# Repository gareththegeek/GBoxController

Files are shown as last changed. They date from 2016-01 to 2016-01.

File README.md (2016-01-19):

# GBoxController

Design for a 31 button USB Windows game controller built using an ATMega328 microcontroller for use with Flight Simulators.

This software was built using the following tools and libraries

<a href="https://www.obdev.at/products/vusb/index.html">V-USB</a><br/>
<a href="http://www.atmel.com/tools/STUDIOARCHIVE.aspx">Atmel Studio 6.2</a><br/>
<a href="https://www.arduino.cc/en/Main/Software">Arduino IDE</a><br/>
<a href="https://code.google.com/p/diy-layout-creator/">DIY Layout Creator</a><br/>
<a href="http://fritzing.org/home/">Fritzing</a><br/>

The device utilises the built in Windows human interface device (HID) driver and should appear in the Control Panel under Game Controllers as a 31 button device.  The controller has:
<ul><li>8 x two way switches (one button each)
<li>4 x three way switches (two buttons each)
<li>5 x rotary encoders with push buttons (three buttons each)</ul>

See the schematics folder for logical and physical circuit diagrams.  I have included png renderings of these diagrams in case you don't have/want the relevant software to view them.

In order to load onto the ATMega chip, I used the Arduino IDE with an Arduino Uno to act as the in service programmer (ISP).  See <a href="https://www.arduino.cc/en/Tutorial/ArduinoISP">this tutorial</a> for an example of how to do this.  The circuit design contains a standard 6 pin ISP socket for this purpose.

The Atmel Studio solution will compile to a binary .hex file.  I found it necessary to modify the Arduino IDE's boards.txt to include an additional entry entitled 'ATMega' which pointed to the location of the compiled binary file in order to use the Arduino ISP.

The controller is designed to send a pulse (button press) each time the state of a switch changes. For example, moving a two way switch up, down, up will result in three separate button presses for the corresponding button.

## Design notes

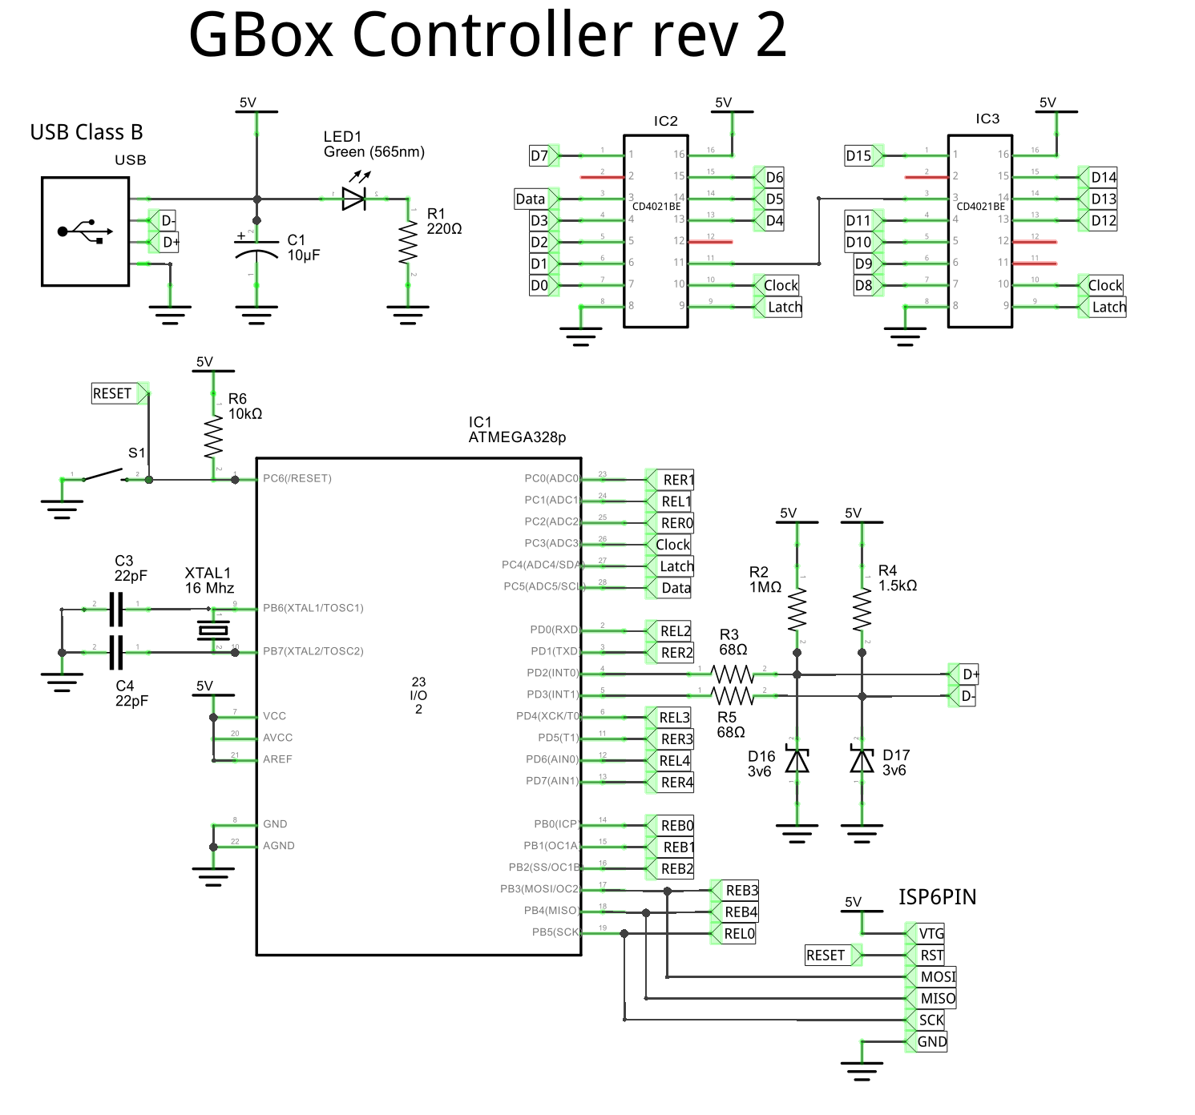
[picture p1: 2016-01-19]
Schematics/Schematic page 1.png

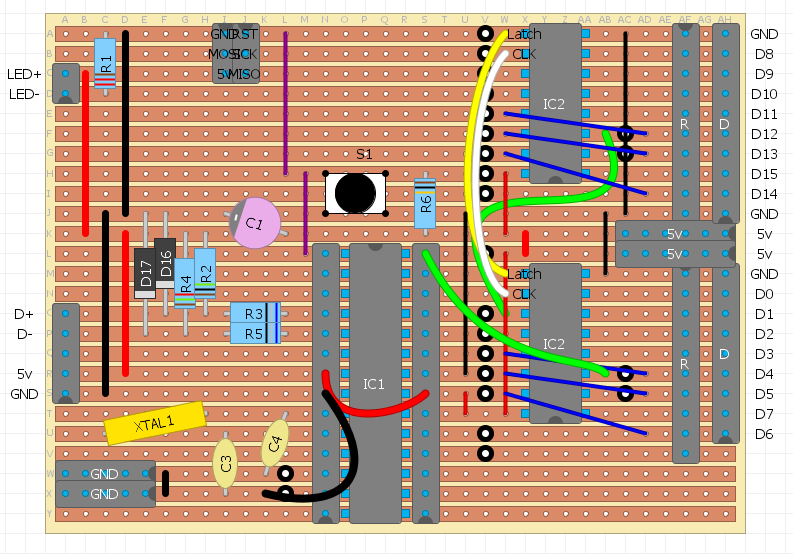
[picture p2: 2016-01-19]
Schematics/Board.png

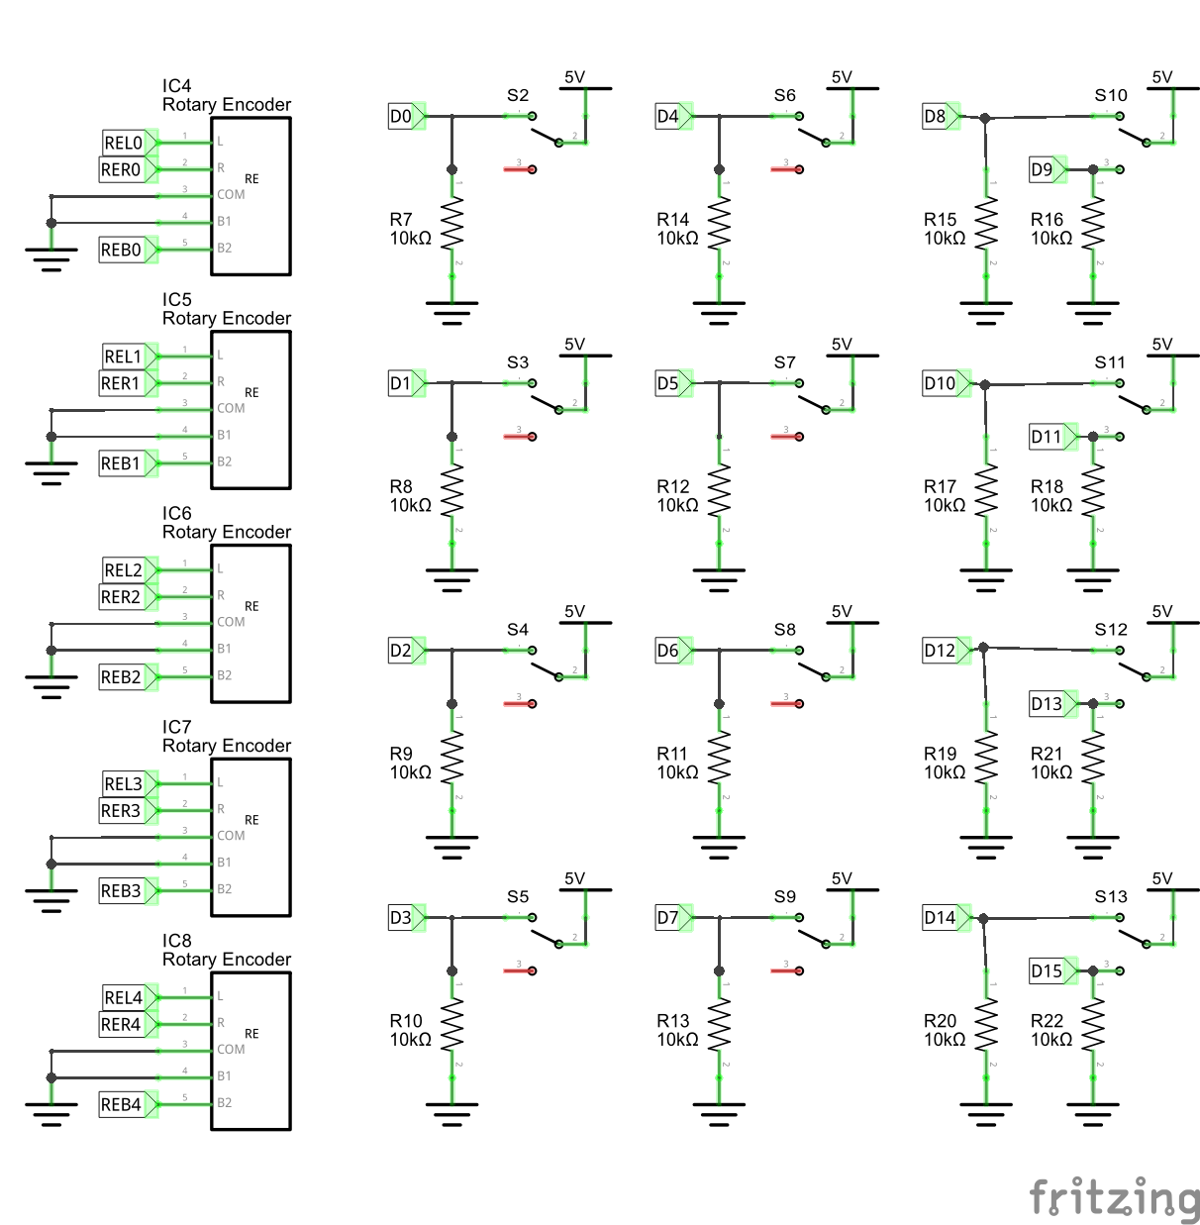
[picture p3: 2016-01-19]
Schematics/Schematic page 2.png

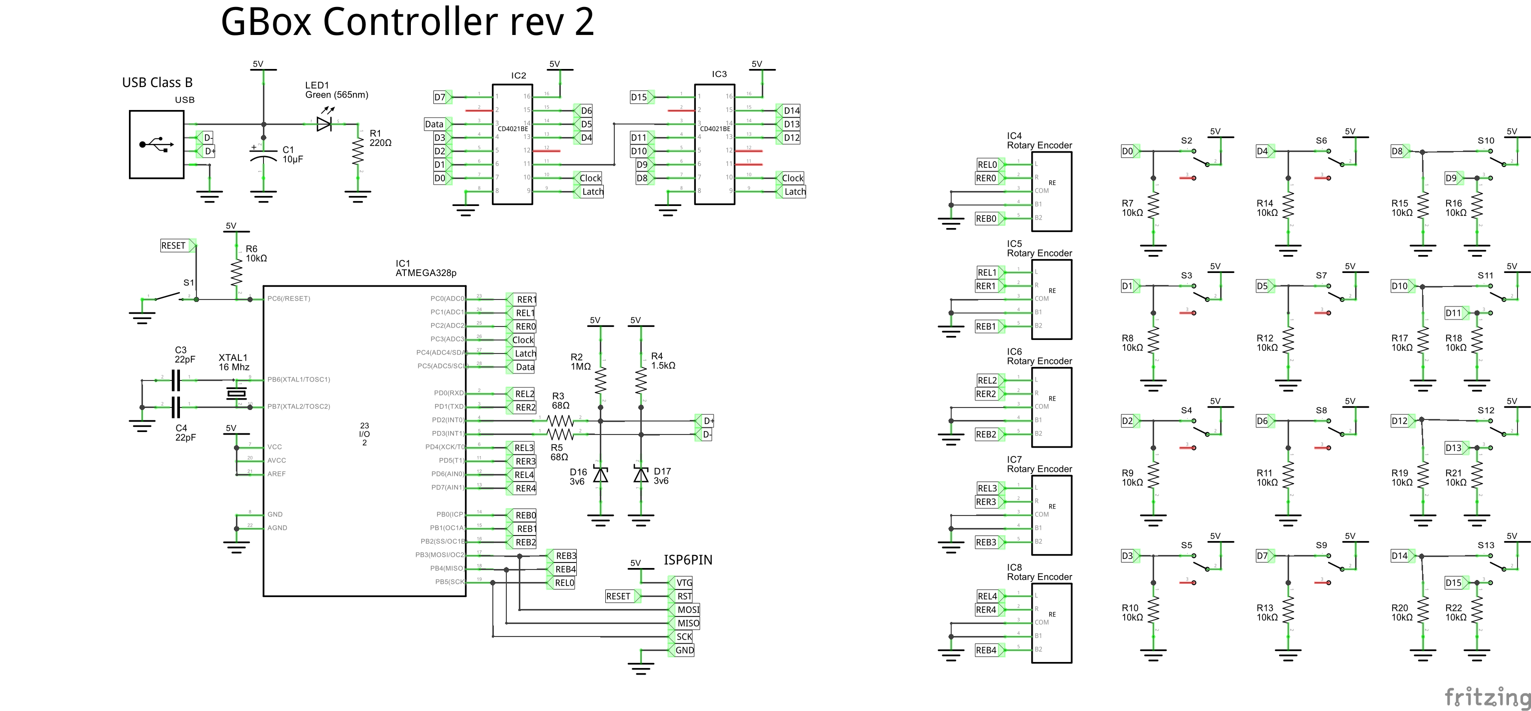
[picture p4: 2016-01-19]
Schematics/Schematic_schem.png

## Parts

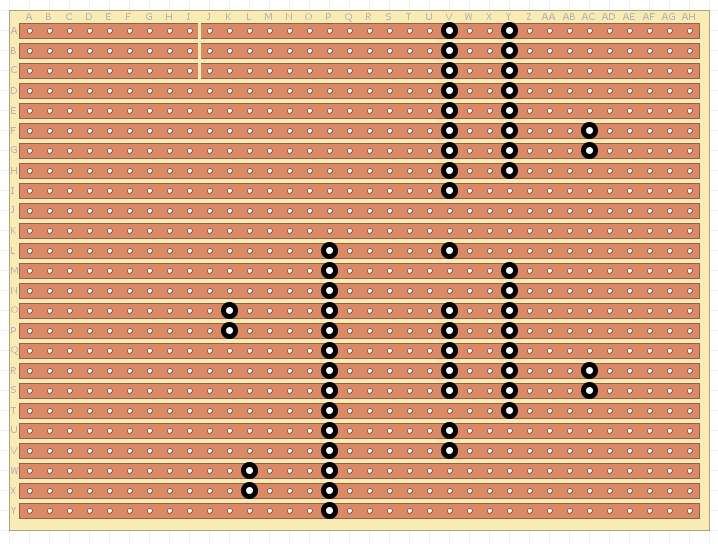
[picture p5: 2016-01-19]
Schematics/Board no components.png

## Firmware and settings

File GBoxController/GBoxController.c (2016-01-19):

// please see http://frank.circleofcurrent.com/index.php?page=hid_tutorial_1
// the "usb_hid_rpt_desc.hid" file needs to be viewed with the HID Descriptor Tool from USB.org

// required headers
#define F_CPU 16000000L
#include <avr/io.h>
#include <avr/wdt.h>
#include <avr/interrupt.h>
#include <util/delay.h>
#include <avr/pgmspace.h>
#include <string.h>

// What the Pins do
// 1   PC6: RESET
// 2   PD0: Rotary Encoder 2 L
// 3   PD1: Rotary Encoder 2 R
// 4   PD2: USB D+
// 5   PD3: USB D-
// 6   PD4: Rotary Encoder 3 L
// 7   VCC: 5v
// 8   GND: 0v
// 9   PB6: CLK
// 10  PB7: CLK
// 11  PD5: Rotary Encoder 3 R
// 12  PD6: Rotary Encoder 4 L
// 13  PD7: Rotary Encoder 4 R
// 14  PB0: REB0 - Rotary Encoder 0 Button
// 15  PB1: REB1 - Rotary Encoder 1 Button
// 16  PB2: REB2 - Rotary Encoder 2 Button
// 17  PB3: REB3 - Rotary Encoder 3 Button
// 18  PB4: REB4 - Rotary Encoder 4 Button
// 19  PB5: Rotary Encoder 0 L
// 20  VCC: 5v
// 21 AREF: 5v 
// 22  GND: 0v
// 23  PC0: Rotary Encoder 1 R
// 24  PC1: Rotary Encoder 1 L
// 25  PC2: Rotary Encoder 0 R
// 26  PC3: Clock - Shift Register
// 27  PC4: Latch - Shift Register
// 28  PC5: Data In - Shift Register

// V-USB
#include "usbdrv/usbdrv.h"

#define CD4021BE_LATCH_PIN PINC4
#define CD4021BE_CLOCK_PIN PINC3
#define CD4021BE_DATA_PIN PINC5

#define REB0 PINB0
#define REB1 PINB1
#define REB2 PINB2
#define REB3 PINB3
#define REB4 PINB4

#define USAGE(x) 0x9, x, // Usage
#define USAGE2(x, y) 0xA, x, y, // Usage
#define USAGE_PAGE(x) 0x5, x, // Usage Page
#define USAGE_PAGE2(x, y) 0x6, x, y, // Usage Page
#define USAGE_MINIMUM(x) 0x19, x, // Usage Minimum
#define USAGE_MAXIMUM(x) 0x29, x, // Usage Maximum
#define COLLECTION(x) 0xA1, x, // Collection
#define END_COLLECTION 0xC0, // End Collection
#define REPORT_ID(x) 0x85, x, // Report
#define REPORT_SIZE(x) 0x75, x, // Report Size
#define REPORT_COUNT(x) 0x95, x, // Report Count
#define LOGICAL_MINIMUM(x) 0x15, x, // Logical Minimum
#define LOGICAL_MINIMUM2(x, y) 0x16, x, y, // Logical Minimum
#define LOGICAL_MINIMUM4(x, y, z, w) 0x17, x, y, z, w, // Logical Minimum
#define LOGICAL_MAXIMUM(x) 0x25, x, // Logical Maximum
#define LOGICAL_MAXIMUM2(x, y) 0x26, x, y, // Logical Maximum
#define LOGICAL_MAXIMUM4(x, y, z, w) 0x27, x, y, z, w, // Logical Maximum
#define PHYSICAL_MINIMUM(x) 0x35, x,
#define PHYSICAL_MAXIMUM(x) 0x45, x,
#define PHYSICAL_MAXIMUM2(x, y) 0x46, x, y,
#define PHYSICAL_MAXIMUM4(x, y, z, w) 0x47, x, y, z, w,
#define OUTPUT(x) 0x91, x, // Output
#define INPUT(x) 0x81, x, // Input
#define FEATURE(x) 0xB1, x, // Feature
#define UNIT(x, y) 0x65, x,
#define UNIT2(x, y) 0x66, x, y,
#define UNIT_EXPONENT(x) 0x55, ((x) & 0x0f),

#define GENERIC_DESKTOP 0x1
#define GAME_PAD 0x5
#define APPLICATION 0x1
#define X 0x30
#define Y 0x31
#define Z 0x32
#define Rx 0x33
#define Ry 0x34
#define Rz 0x35
#define SLIDER 0x36
#define DIAL 0x37
#define DATA_VAR_ABS 0x2
#define CNST_VAR_ABS 0x3
#define BUTTON 0x9
#define PHYSICAL 0x0

PROGMEM const char usbHidReportDescriptor[USB_CFG_HID_REPORT_DESCRIPTOR_LENGTH] = {
	USAGE_PAGE(GENERIC_DESKTOP)
	USAGE(GAME_PAD)
	COLLECTION(APPLICATION)
		COLLECTION(PHYSICAL)
			USAGE_PAGE(BUTTON)
			USAGE_MINIMUM(1)
			USAGE_MAXIMUM(31)
			LOGICAL_MINIMUM(0)
			LOGICAL_MAXIMUM(1)
			REPORT_COUNT(31)
			REPORT_SIZE(1)
			INPUT(DATA_VAR_ABS)
			REPORT_COUNT(1)
			REPORT_SIZE(1)
			INPUT(CNST_VAR_ABS)
		END_COLLECTION
	END_COLLECTION
};

typedef struct
{
	uint8_t buttons0;
	uint8_t buttons1;
	uint8_t buttons2;
	uint8_t buttons3;
	
} gamepad_report_t;

static uint8_t idle_rate = 500 / 4; // see HID1_11.pdf sect 7.2.4
static uint8_t protocol_version = 0; // see HID1_11.pdf sect 7.2.6

static volatile gamepad_report_t gamepad_report;
static volatile gamepad_report_t gamepad_report_old;

usbMsgLen_t usbFunctionSetup(uint8_t data[8])
{
	// see HID1_11.pdf sect 7.2 and http://vusb.wikidot.com/driver-api
	usbRequest_t *rq = (void *)data;

	if ((rq->bmRequestType & USBRQ_TYPE_MASK) != USBRQ_TYPE_CLASS)
		return 0; // ignore request if it's not a class specific request

	// see HID1_11.pdf sect 7.2
	switch (rq->bRequest)
	{
		case USBRQ_HID_GET_IDLE:
			usbMsgPtr = &idle_rate; // send data starting from this byte
			return 1; // send 1 byte
		case USBRQ_HID_SET_IDLE:
			idle_rate = rq->wValue.bytes[1]; // read in idle rate
			return 0; // send nothing
		case USBRQ_HID_GET_PROTOCOL:
			usbMsgPtr = &protocol_version; // send data starting from this byte
			return 1; // send 1 byte
		case USBRQ_HID_SET_PROTOCOL:
			protocol_version = rq->wValue.bytes[1];
			return 0; // send nothing
		case USBRQ_HID_GET_REPORT:
			usbMsgPtr = (uchar*)&gamepad_report;
			return sizeof(gamepad_report);
		case USBRQ_HID_SET_REPORT: // no "output" or "feature" implemented, so ignore
			return 0; // send nothing
		default: // do not understand data, ignore
			return 0; // send nothing
	}
}

// this function is used to guarantee that the data is sent to the computer once
void usbSendHidReport(uchar * data, uchar len)
{
	while(1)
	{
		usbPoll();
		if (usbInterruptIsReady())
		{
			usbSetInterrupt(data, len);
			break;
		}
	}
}

static void hardwareInit(void)
{
	// TODO: Not sure but I think this may be required if I implement the watchdog
	
	//uchar i = 0;
	//uchar j = 0;

	//PORTB	= 0xff;   // Activate all pull-ups
	//DDRB	= 0x00;   // All pins input
	//PORTC	= 0xff;   // Activate all pull-ups
	//DDRC	= 0x00;   // All pins input
	//PORTD	= 0xfa;   // 1111 1010 bin: activate pull-ups except on USB lines
	//DDRD	= 0x05;   // 0000 0101 bin: all pins input except USB (-> USB reset)
	//while(--j)
	//{
		//// USB Reset by device only required on Watchdog Reset
		//while(--i); // Delay >10ms for USB reset
	//}
	//DDRD = 0x00;    // 0000 0000 bin: remove USB reset condition
	
	// Configure timer 0 for a rate of 16M/(1024 * 256) = 61.04 Hz (~16ms)
	//TCCR0B = 5;      // Timer0 prescaler: 1024
	
	//DDRD |= (1<<DDD1);
	//PORTD |= (1<<PORTD1);
	
	// Digital Pins //
	
	PORTB = 0xff;	// Activate pull-ups
	DDRB = 0x00;	// All pins are input
	PORTD = 0xf3;	// Activate pull-ups (except USB pins)
	DDRD = 0x00;	// All pins are input
	
	PORTC = 0xc7;	// Activate pull-ups (except shift register)
	
	DDRC =
		(1 << CD4021BE_LATCH_PIN) |
		(1 << CD4021BE_CLOCK_PIN);	// Enable write on latch and clock pins only
		
	// Enable interrupts for rotary encoders
	PCMSK0 |= (1 << PCINT5);
	PCMSK1 |= (1 << PCINT8) | (1 << PCINT9) | (1 << PCINT10);
	PCMSK2 |= (1 << PCINT16) | (1 << PCINT17) | (1 << PCINT20) | (1 << PCINT21) | (1 << PCINT22) | (1 << PCINT23);
	
	PCICR |= (1 << PCIE0);
	PCICR |= (1 << PCIE1);
	PCICR |= (1 << PCIE2);
}

#define CHANGE_BUFFER_LENGTH 128
static volatile gamepad_report_t changeBuffer[CHANGE_BUFFER_LENGTH];
static volatile uint8_t changeBufferIndex;

static volatile gamepad_report_t currentState;
static volatile gamepad_report_t previousState;

#define ROTARY_ENCODER_COUNT 10
static int8_t encval[ROTARY_ENCODER_COUNT];
static uint8_t old_AB[ROTARY_ENCODER_COUNT];

static const int8_t enc_states [] PROGMEM =
	{0,-1,1,0,1,0,0,-1,-1,0,0,1,0,1,-1,0};  //encoder lookup table

static void readEncoder(uint8_t reindex, uint8_t data, uint8_t leftValue, uint8_t rightValue)
{	
	old_AB[reindex] <<=2;  //remember previous state
	old_AB[reindex] |= data;
	encval[reindex] += pgm_read_byte(&(enc_states[( old_AB[reindex] & 0x0f )]));
	
	if (encval[reindex] > 3)
	{
		encval[reindex] = 0;
		
		if(leftValue >= 8)
		{
			leftValue -= 8;
			previousState.buttons3 &= ~(1 << leftValue);
			currentState.buttons3 |= (1 << leftValue);
		}
		else
		{
			previousState.buttons2 &= ~(1 << leftValue);
			currentState.buttons2 |= (1 << leftValue);
		}
	}
	else if (encval[reindex] < -3)
	{
		encval[reindex] = 0;
		
		if(rightValue >= 8)
		{
			rightValue -= 8;
			previousState.buttons3 &= ~(1 << rightValue);
			currentState.buttons3 |= (1 << rightValue);
		}
		else
		{
			previousState.buttons2 &= ~(1 << rightValue);
			currentState.buttons2 |= (1 << rightValue);
		}
	}
}

#define ROTARY_ENCODER0 readEncoder(0, ( (PINB & (1 << PINB5)) >> 4 ) | ( (PINC & (1 << PINC2)) >> 2 ), 5, 6)
#define ROTARY_ENCODER1 readEncoder(1, ( (PINC & ( (1 << PINC0) | (1 << PINC1) ))      ), 7, 8)
#define ROTARY_ENCODER2 readEncoder(2, ( (PIND & ( (1 << PIND0) | (1 << PIND1) ))      ), 9, 10)
#define ROTARY_ENCODER3 readEncoder(3, ( (PIND & ( (1 << PIND4) | (1 << PIND5) )) >> 4 ), 11, 12)
#define ROTARY_ENCODER4 readEncoder(4, ( (PIND & ( (1 << PIND6) | (1 << PIND7) )) >> 6 ), 13, 14)

static uint8_t previousPINB;
static uint8_t previousPINC;
static uint8_t previousPIND;

ISR(PCINT0_vect)
{
	// Figure out which pin triggered the interrupt
	
	uint8_t pinB = PINB & 0x20; /*00100000 PB5*/
	
	uint8_t changeB = previousPINB ^ pinB;
	
	previousPINB = pinB;
	
	if (changeB != 0)
	{
		// Rotary Encoder 0 on pins PB5 and PC3
		ROTARY_ENCODER0;
	}
}

ISR(PCINT1_vect)
{
	// Figure out which pin triggered the interrupt
	
	uint8_t pinC = PINC & 0x07; /*00000111 PB0-PB2*/
	
	uint8_t changeC = previousPINC ^ pinC;
	
	previousPINC = pinC;
	
	if (changeC & (1 << PINC2))
	{
		// Rotary Encoder 0 on pins PB5 and PC2
		ROTARY_ENCODER0;
	}
	
	if(changeC & ( (1 << PINC0) | (1 << PINC1) ))
	{
		// Rotary Encoder 1 on pins PC0 and PC1
		ROTARY_ENCODER1;
	}
}

ISR(PCINT2_vect)
{
	// Figure out which pin triggered the interrupt
	
	uint8_t pinD = PIND & 0xf3; /*11110011 PD0-PD1 PD4-PD7*/
	
	uint8_t changeD = previousPIND ^ pinD;
	
	previousPIND = pinD;
	
	if(changeD != 0)
	{
		if (changeD & ((1 << PIND0) | (1 << PIND1)))
		{
			// Rotary Encoder 2 on pins PD0 and PD1
			ROTARY_ENCODER2;
		}
		if (changeD & ((1 << PIND4) | (1 << PIND5)))
		{
			// Rotary Encoder 3 on pins PD4 and PD5
			ROTARY_ENCODER3;
		}
		if (changeD & ((1 << PIND6) | (1 << PIND7)))
		{
			// Rotary Encoder 4 on pins PD6 and PD7
			ROTARY_ENCODER4;
		}
	}
}

static void clockPulse(uint8_t clockPin)
{
	PINC |= (1 << clockPin);
	_delay_us(0.2d);
	PINC &= ~(1 << clockPin);
	_delay_us(0.2d);
}

static void latch(uint8_t latchPin)
{
	//Pulse the latch pins:
	//set them to 1 to collect parallel data
	PINC |= (1 << latchPin);
	//set it to 1 to collect parallel data, wait
	_delay_us(20.0d);
	//set it to 0 to transmit data serially
	PINC &= ~(1 << latchPin);
	//_delay_us(10.0d);
}

static uint8_t shiftIn(uint8_t dataPin, uint8_t clockPin)
{	
	int8_t i;
	uint8_t temp;
	uint8_t data = 0;
	
	clockPulse(clockPin);
	
	for (i = 7; i >= 0; i--)
	{
		temp = PINC;
		_delay_us(0.2d);
		
		temp &= (1 << dataPin);
		temp >>= dataPin;
		
		data |= (temp << i);
		
		// HACK: Contrary to all tutorials and the 4021 chip's data-,
		// I seem to have to use two clock pulses instead of one.
		// Clearly I have misunderstood something here but this code
		// works so I'm going with it!
		clockPulse(clockPin);
		clockPulse(clockPin);
	}
	
	return data;
}

static void updateReport()
{	
	latch(CD4021BE_LATCH_PIN);
	
	currentState.buttons0 = shiftIn(CD4021BE_DATA_PIN, CD4021BE_CLOCK_PIN);
	currentState.buttons1 = shiftIn(CD4021BE_DATA_PIN, CD4021BE_CLOCK_PIN);
	currentState.buttons2 = ~PINB & 0x1f /*00011111 = PB0-PB4*/ | (currentState.buttons2 & 0xe0); /*11100000 = REL0 RER0 REL1*/
	// currentState.buttons3 = RER1 REL2 RER2 REL3 RER3 REL4 RER4
	
	uint8_t change0 = currentState.buttons0 ^ previousState.buttons0;
	uint8_t change1 = currentState.buttons1 ^ previousState.buttons1;
	uint8_t change2 = (currentState.buttons2 & 0x1f) | ( (currentState.buttons2 ^ previousState.buttons2) & 0xe0 );
	uint8_t change3 = currentState.buttons3 ^ previousState.buttons3;
	
	memcpy(&previousState, &currentState, sizeof(gamepad_report_t));
	
	for (uint8_t i = 0; i < CHANGE_BUFFER_LENGTH; i++)
	{
		changeBuffer[i].buttons0 |= change0;
		changeBuffer[i].buttons1 |= change1;
		changeBuffer[i].buttons2 |= change2;
		changeBuffer[i].buttons3 |= change3;
	}
	
	memcpy(&gamepad_report, &changeBuffer[changeBufferIndex], sizeof(gamepad_report_t));
	
	changeBuffer[changeBufferIndex].buttons0 = 0;
	changeBuffer[changeBufferIndex].buttons1 = 0;
	changeBuffer[changeBufferIndex].buttons2 = 0;
	changeBuffer[changeBufferIndex].buttons3 = 0;
	
	changeBufferIndex++;
	changeBufferIndex %= CHANGE_BUFFER_LENGTH;
}

int main()
{
	// TODO: watchdog
	wdt_disable(); // no watchdog, just because I'm lazy
	
	//position = 0;
	
	TCCR1B = _BV(CS12) | _BV(CS11); // timer is initialized, used to keep track of idle period
	
	hardwareInit();
	
	usbInit(); // start v-usb
    usbDeviceDisconnect(); // enforce USB re-enumeration, do this while interrupts are disabled!
	_delay_ms(250);
    usbDeviceConnect();
	
    sei(); // enable interrupts
	
	uint8_t to_send = 1; // boolean, true for first time
	
	while (1)
	{
		usbPoll();
		
		/*
		 * this area is where you should set the movement
		 * and button values of the reports using the input
		 * method of your choice
		 *
		*/
		
		updateReport();
		
		// determine whether or not the report should be sent
		if ((TCNT1 > ((4 * (F_CPU / 1024000)) * idle_rate) || TCNT1 > 0x7FFF) && idle_rate != 0)
		{// using idle rate
			to_send = 1;
		}
		else
		{// or if data has changed
			if (memcmp(&gamepad_report, &gamepad_report_old, sizeof(gamepad_report_t)) != 0)
			{
				to_send = 1;
			}
		}
		
		usbPoll();
		if (to_send != 0)
		{
			// send the data if needed
			usbSendHidReport((uchar*)&gamepad_report, sizeof(gamepad_report_t));
			TCNT1 = 0; // reset timer
		}
		
		usbPoll();
		
		memcpy(&gamepad_report_old, &gamepad_report, sizeof(gamepad_report_t));
		
		to_send = 0; // reset flag
	}
	
	return 0;
}

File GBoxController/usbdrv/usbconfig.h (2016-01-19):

/* Name: usbconfig.h
 * Project: V-USB, virtual USB port for Atmel's(r) AVR(r) microcontrollers
 * Author: Christian Starkjohann
 * Creation Date: 2005-04-01
 * Tabsize: 4
 * Copyright: (c) 2005 by OBJECTIVE DEVELOPMENT Software GmbH
 * License: GNU GPL v2 (see License.txt), GNU GPL v3 or proprietary (CommercialLicense.txt)
 * This Revision: $Id: usbconfig-prototype.h 785 2010-05-30 17:57:07Z cs $
 */

#ifndef __usbconfig_h_included__
#define __usbconfig_h_included__

/*
General Description:
This file is an example configuration (with inline documentation) for the USB
driver. It configures V-USB for USB D+ connected to Port D bit 2 (which is
also hardware interrupt 0 on many devices) and USB D- to Port D bit 4. You may
wire the lines to any other port, as long as D+ is also wired to INT0 (or any
other hardware interrupt, as long as it is the highest level interrupt, see
section at the end of this file).
+ To create your own usbconfig.h file, copy this file to your project's
+ firmware source directory) and rename it to "usbconfig.h".
+ Then edit it accordingly.
*/

/* ---------------------------- Hardware Config ---------------------------- */

#define USB_CFG_IOPORTNAME      D
/* This is the port where the USB bus is connected. When you configure it to
 * "B", the registers PORTB, PINB and DDRB will be used.
 */
#define USB_CFG_DMINUS_BIT      3
/* This is the bit number in USB_CFG_IOPORT where the USB D- line is connected.
 * This may be any bit in the port.
 */
#define USB_CFG_DPLUS_BIT       2
/* This is the bit number in USB_CFG_IOPORT where the USB D+ line is connected.
 * This may be any bit in the port. Please note that D+ must also be connected
 * to interrupt pin INT0! [You can also use other interrupts, see section
 * "Optional MCU Description" below, or you can connect D- to the interrupt, as
 * it is required if you use the USB_COUNT_SOF feature. If you use D- for the
 * interrupt, the USB interrupt will also be triggered at Start-Of-Frame
 * markers every millisecond.]
 */
#define USB_CFG_CLOCK_KHZ       (16000)
/* Clock rate of the AVR in kHz. Legal values are 12000, 12800, 15000, 16000,
 * 16500, 18000 and 20000. The 12.8 MHz and 16.5 MHz versions of the code
 * require no crystal, they tolerate +/- 1% deviation from the nominal
 * frequency. All other rates require a precision of 2000 ppm and thus a
 * crystal!
 * Since F_CPU should be defined to your actual clock rate anyway, you should
 * not need to modify this setting.
 */
#define USB_CFG_CHECK_CRC       0
/* Define this to 1 if you want that the driver checks integrity of incoming
 * data packets (CRC checks). CRC checks cost quite a bit of code size and are
 * currently only available for 18 MHz crystal clock. You must choose
 * USB_CFG_CLOCK_KHZ = 18000 if you enable this option.
 */

/* ----------------------- Optional Hardware Config ------------------------ */

/* #define USB_CFG_PULLUP_IOPORTNAME   D */
/* If you connect the 1.5k pullup resistor from D- to a port pin instead of
 * V+, you can connect and disconnect the device from firmware by calling
 * the macros usbDeviceConnect() and usbDeviceDisconnect() (see usbdrv.h).
 * This constant defines the port on which the pullup resistor is connected.
 */
/* #define USB_CFG_PULLUP_BIT          4 */
/* This constant defines the bit number in USB_CFG_PULLUP_IOPORT (defined
 * above) where the 1.5k pullup resistor is connected. See description
 * above for details.
 */

/* --------------------------- Functional Range ---------------------------- */
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

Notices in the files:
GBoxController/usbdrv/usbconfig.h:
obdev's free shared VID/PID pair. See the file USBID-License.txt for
